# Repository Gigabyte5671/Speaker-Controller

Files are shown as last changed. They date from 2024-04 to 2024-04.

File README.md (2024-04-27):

# Speaker Controller
**Automatically turns my desk speakers on/off when I change the audio output in Windows.**

Well, that's what I'm using this project for anyway. Although, it's essentially just a smart power bar - you can use it to switch any household appliance on/off.

<br>

> [!WARNING]
> This project deals with dangerous mains voltages. Do not attempt to replicate this project unless you are experienced with the hazards involved and are using the appropriate safety equipment.

<br>

## Bill of Materials
Components and materials I used:
- [Duinotech Leonardo Tiny](https://www.jaycar.co.nz/leonardo-tiny-atmega32u4-main-board/p/XC4431)
- [Arduino Compatible 5V Relay](https://www.jaycar.co.nz/arduino-compatible-5v-relay/p/XC4419)
- [This random power bar](https://www.kmart.co.nz/product/arlec-4-outlet-surge-protected-powerboard-42153580/)
- [10⨯ M2.5⨯9 self-tapping screws](https://www.bunnings.co.nz/zenith-4g-x-9mm-sheet-metal-self-tappers-pan-head-slotted-phillips-drive-screws-100-pack_p2435782)
- ~20m/~60g of [1.75mm filament](https://www.bits4bots.co.nz/products/esun-pla-1-75mm-1kg?variant=43675171356827)

<br>

## Circuit
This is a rough diagram of the circuit I'm using to control the speakers:  
full circuit diagram

In reality, all of the discreet components are part of [this board](https://www.jaycar.co.nz/arduino-compatible-5v-relay/p/XC4419), and connected to the [Arduino](https://www.jaycar.co.nz/leonardo-tiny-atmega32u4-main-board/p/XC4431) like so:  
simple circuit diagram

<br>

## Code
### Arduino
Code for the Arduino is located in the [`sketch`](./sketch/) directory.  
This program simply listens for characters being sent by the USB host and toggles the relay's state accordingly. If the program receives a `'1'` the relay is turned on, `'0'` the relay is turned off. The program also needs to receive a heartbeat message (`'2'`) at least once every 5 seconds for the relay to stay on.

### PC
The script to be run on the connected PC is in the [`controller`](./controller/) directory.  
This script runs in the background, polling the registry for updates to the default audio output device. When the default device changes to one of the specified **"active"** devices, it instructs the Arduino to turn the relay **on**. When the default device changes to one of the specified **"inactive"** devices, it instructs the Arduino to turn the relay **off**.

> [!TIP]
> You can customise the list of "active" and "inactive" audio devices in the [config](./controller/config.js) file.

> [!NOTE]
> You'll need to run `cd controller && npm i` before running this script for the first time.

<br>

## Housing
The [`models`](./models/) directory contains some housing models that fit with [my particular power bar](https://www.kmart.co.nz/product/arlec-4-outlet-surge-protected-powerboard-42153580/).

You can also find the [model source on OnShape](https://cad.onshape.com/documents/b996f80e98ba7dbd92c3a90e/w/50b2495923acaf03b7d63635/e/e429f6e0665596681b5c2419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).

I printed these with eSun White PLA+, and the following settings:
- 0.4mm nozzle
- 0.2mm layer height
- 3 wall layers
- 15% infill density

<br>

## Images
Fully assembled:  
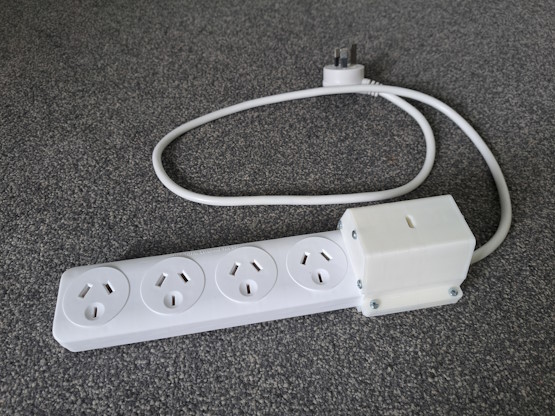
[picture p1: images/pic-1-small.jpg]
The assembled device


The Arduino and relay are slid into the right side of the housing:  
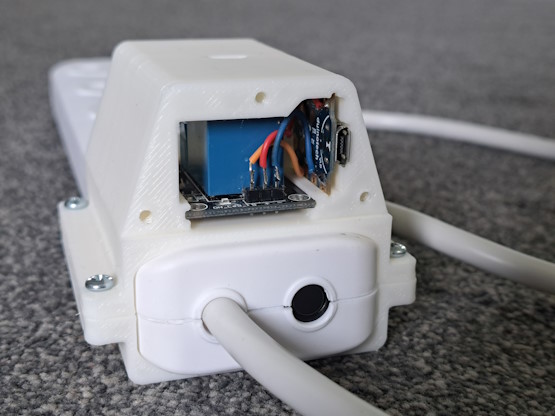
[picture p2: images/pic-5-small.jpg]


With the cover on, the USB port is accessible from this side of the device:  
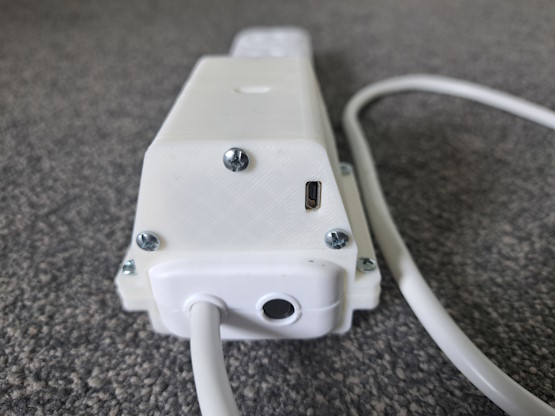
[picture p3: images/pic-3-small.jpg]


On the opposite side, the two ends of the live wire are inserted into the screw terminals on the relay board:  
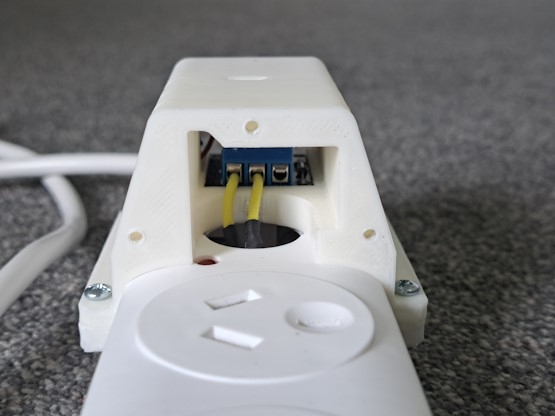
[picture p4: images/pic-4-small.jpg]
Inside the left side of the device


The terminals can be tightened down through a small hole in the top of the housing:  
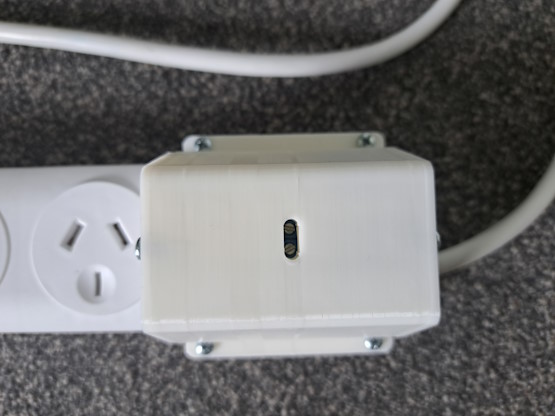
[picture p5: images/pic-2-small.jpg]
Top of the device


*You can find full-size versions of these images in the [`images`](./images/) directory.*

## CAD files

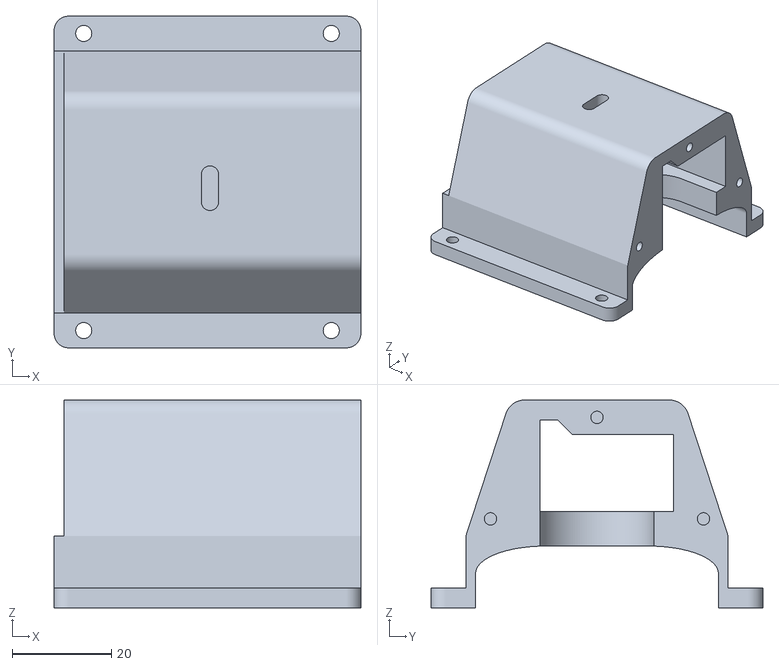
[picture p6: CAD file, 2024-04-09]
models/Part_2.stl
62.0 x 67.0 x 42.0

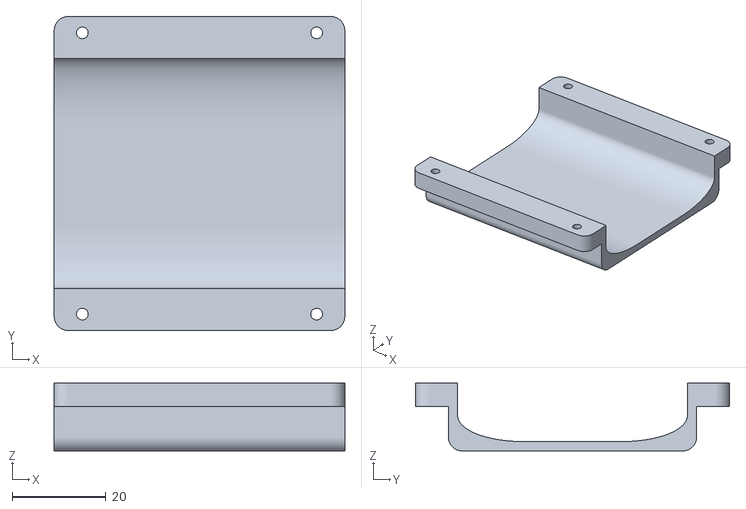
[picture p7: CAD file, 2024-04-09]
models/Part_1.stl
62.0 x 67.0 x 14.5

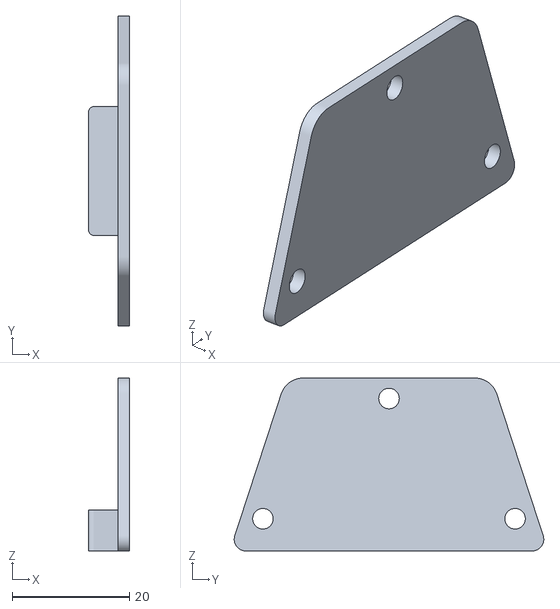
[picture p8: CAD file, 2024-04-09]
models/Part_4.stl
7.00 x 52.8 x 29.5

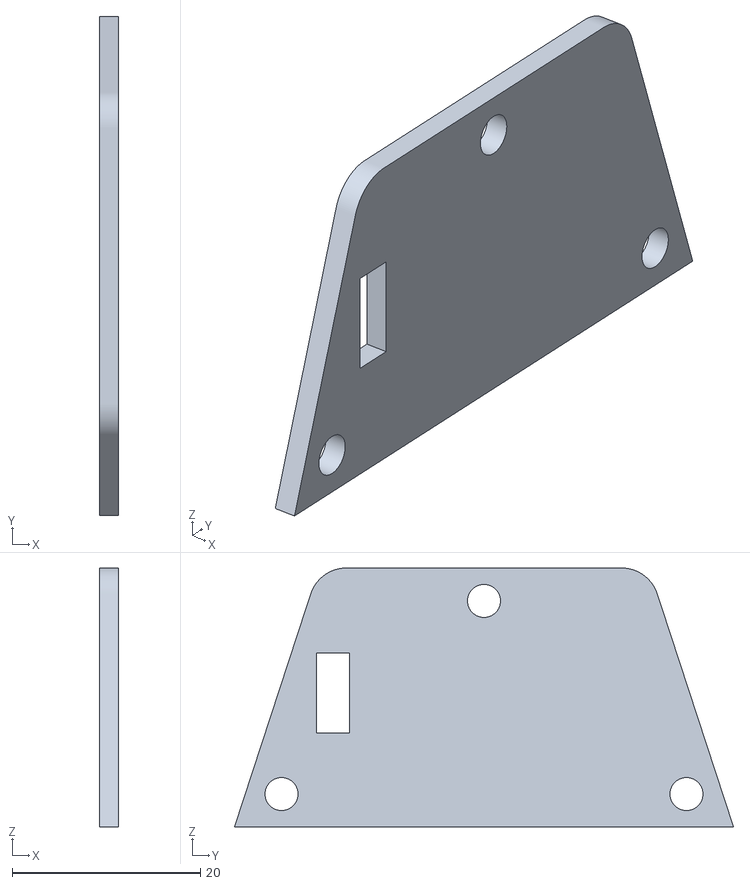
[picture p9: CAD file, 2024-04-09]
models/Part_3.stl
2.00 x 53.0 x 27.5

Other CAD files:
models/Part_1.obj
models/Part_2.obj
models/Part_3.obj
models/Part_4.obj

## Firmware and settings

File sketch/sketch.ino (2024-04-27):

int relay = 9;
int missedHeartbeats = 0;
int maxMissedHeartbeats = 20;

void setup() {
  pinMode(relay, OUTPUT);
  Serial.begin(9600);
}

void loop() {
  missedHeartbeats++;
  if (Serial.available()) {
    char input = (char)Serial.read();
    if (input == '0') {
      digitalWrite(relay, LOW);
    } else if (input == '1') {
      digitalWrite(relay, HIGH);
    } else if (input == '2') {
      missedHeartbeats = 0;
    }
    input = ' ';
  }
  if (missedHeartbeats > maxMissedHeartbeats) {
    digitalWrite(relay, LOW);
  }
  delay(250);
}

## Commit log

2024-04-04 Create Arduino sketch
2024-04-07 Handle cases where the power switch is disconnected
2024-04-07 Create circuit diagrams
2024-04-09 Create housing models
    [Part_1.obj, Part_1.stl, Part_2.obj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]
2024-04-10 Move the circuit diagrams to the `images/` directory
2024-04-10 Add pics of the device
2024-04-10 Update circuit diagrams
    More accurately represent the Arduino board.
2024-04-10 Add bill of materials
2024-04-10 Make the controller significantly more configurable
    - Supports listening to multiple audio devices.
    - Audio devices can now be targeted by name instead of by key.
    - Automatically retrieves the registry keys for the specified audio devices.
2024-04-13 Add a menu to the system tray
    - Allows the relay to be manually turned on/off.
    - Visually shows the expected state of the relay.
2024-04-13 Also update tray tooltip with relay state
2024-04-27 Require a heartbeat to keep the relay active
    Allows the relay to automatically turn off when the host PC is shutdown, goes to sleep, or is otherwise disconnected.
